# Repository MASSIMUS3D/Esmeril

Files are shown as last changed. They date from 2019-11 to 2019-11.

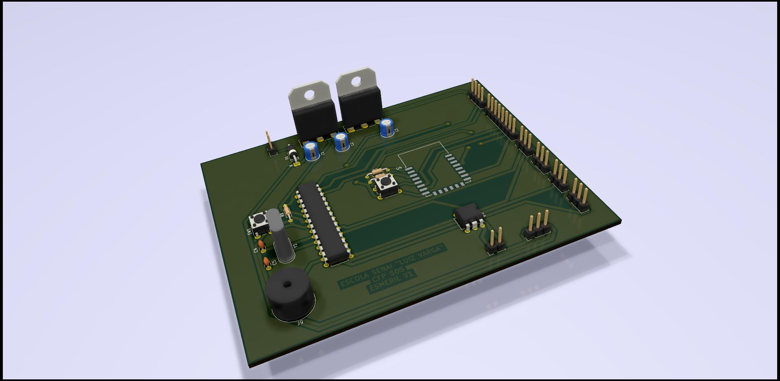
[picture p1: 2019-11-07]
Esmeril-Placa para banca avaliadora/Placa Esmeril.jpg

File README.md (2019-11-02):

# Esmeril
Projeto de adequação de esmeril para NR12 e uso em instituições educacionais
O projeto visa a adequacao de um Esmeril de uso comum para a NR12, tendo em vista os perigos de uso principalmente no ambiente educacionalç,onde os alunos ainda estao aprendendo o uso correto e ainda estao espostos  a ferimentos graves.

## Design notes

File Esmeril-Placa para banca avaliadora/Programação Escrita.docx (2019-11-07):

#include <Servo.h>

#include <U8glib.h>

U8GLIB_SSD1306_128X64 u8g(U8G_I2C_OPT_DEV_0|U8G_I2C_OPT_NO_ACK|U8G_I2C_OPT_FAST);

Servo servo_9;

void setup(){

servo_9.attach(9);

Serial.begin(9600);

pinMode(13, OUTPUT);

servo_9.write(0);

delay(0);

digitalWrite(13,LOW);

pinMode(6, INPUT);

pinMode(5, INPUT);

u8g.firstPage();

do {

u8g.setFont(u8g_font_unifont);

} while( u8g.nextPage());

delay(1000);

pinMode(7, OUTPUT);

pinMode(3, INPUT);

pinMode(4, INPUT);

pinMode(2, INPUT);

}

void loop(){

// INICIA COM SERVO FECHADO E COM O MOTOR DESLIGADO

// LEITURA DO PIR E INFRAVERMELHO.

// TODOS EM NIVEL BAIXO

if (digitalRead(6) == HIGH && digitalRead(5) == LOW) {

// SAUDACAO

u8g.firstPage();

do {

u8g.setPrintPos(0,14);

u8g.print("SENAI");

u8g.setPrintPos(0,30);

u8g.print("");

u8g.setPrintPos(0,46);

u8g.print("LUIZ VARGA");

u8g.setPrintPos(0,62);

u8g.print("");

}

while( u8g.nextPage() );

delay(3000);

while (digitalRead(5) == HIGH) {

Serial.println("Limite de Segurança");

u8g.firstPage();

do {

u8g.setPrintPos(0,14);

u8g.print("MAO");

u8g.setPrintPos(0,30);

u8g.print("PROXIMA");

u8g.setPrintPos(0,46);

u8g.print("AO");

u8g.setPrintPos(0,62);

u8g.print("REBOLO");

}

while( u8g.nextPage() );

digitalWrite(13,LOW);

servo_9.write(0);

delay(1000);

tone(7,131,1000);

}

while (digitalRead(6) == LOW) {

Serial.println("Infravermelho Lateral");

u8g.firstPage();

do {

u8g.setPrintPos(0,14);

u8g.print("USINAGEM");

u8g.setPrintPos(0,30);

u8g.print("LATERAL");

u8g.setPrintPos(0,46);

u8g.print("NAO");

u8g.setPrintPos(0,62);

u8g.print("PERMITIDA");

}

while( u8g.nextPage() );

digitalWrite(13,LOW);

servo_9.write(0);

delay(1000);

tone(7,988,1000);

}

while (digitalRead(3) == LOW) {

Serial.println("Abaixar Proteção");

u8g.firstPage();

do {

u8g.setPrintPos(0,14);

u8g.print("ABAIXAR");

u8g.setPrintPos(0,30);

u8g.print("PROTECAO");

u8g.setPrintPos(0,46);

u8g.print("DE");

u8g.setPrintPos(0,62);

u8g.print("ACRILICO");

}

while( u8g.nextPage() );

digitalWrite(13,LOW);

servo_9.write(0);

delay(1000);

}

while (digitalRead(4) == LOW) {

Serial.println("Posicionar Material");

u8g.firstPage();

do {

u8g.setPrintPos(0,14);

u8g.print("POSICIONAR");

u8g.setPrintPos(0,30);

u8g.print("MATERIAL");

u8g.setPrintPos(0,46);

u8g.print("NO");

u8g.setPrintPos(0,62);

u8g.print("SUPORTE");

}

while( u8g.nextPage() );

digitalWrite(13,LOW);

servo_9.write(0);

delay(1000);

}

while (digitalRead(2) == LOW) {

Serial.println("Aproximar Cartão");

u8g.firstPage();

do {

u8g.setPrintPos(0,14);

u8g.print("APROXIMAR");

u8g.setPrintPos(0,30);

u8g.print("CARTAO");

u8g.setPrintPos(0,46);

u8g.print("NO");

u8g.setPrintPos(0,62);

u8g.print("LEITOR RFID");

}

while( u8g.nextPage() );

digitalWrite(13,LOW);

servo_9.write(0);

delay(1000);

}

delay(1000);

// LEITURA DO PIR E INFRAVERMELHO.

// TODOS EM NIVEL BAIXO

while ((digitalRead(3) && digitalRead(4)) == HIGH && (digitalRead(6) == HIGH && digitalRead(5) == LOW)) {

servo_9.write(160);

delay(1000);

digitalWrite(13,HIGH);

Serial.println("Ligado");

u8g.firstPage();

do {

u8g.setPrintPos(0,14);

u8g.print("REBOLO");

u8g.setPrintPos(0,30);

u8g.print("LIGADO");

u8g.setPrintPos(0,46);

u8g.print("");

u8g.setPrintPos(0,62);

u8g.print("CUIDADO");

}

while( u8g.nextPage() );

}

digitalWrite(13,LOW);

Serial.println("REBOLO EM INERCIA");

u8g.firstPage();

do {

u8g.setPrintPos(0,14);

u8g.print("REBOLO");

u8g.setPrintPos(0,30);

u8g.print("EM");

u8g.setPrintPos(0,46);

u8g.print("INERCIA");

u8g.setPrintPos(0,62);

u8g.print("AGUARDE");

}

while( u8g.nextPage() );

servo_9.write(0);

delay(1000);

tone(7,440,5000);

delay(1000);

tone(7,440,5000);

delay(1000);

tone(7,440,5000);

delay(1000);

} else {

digitalWrite(13,LOW);

Serial.println("Desligado");

servo_9.write(0);

delay(1000);

}

}

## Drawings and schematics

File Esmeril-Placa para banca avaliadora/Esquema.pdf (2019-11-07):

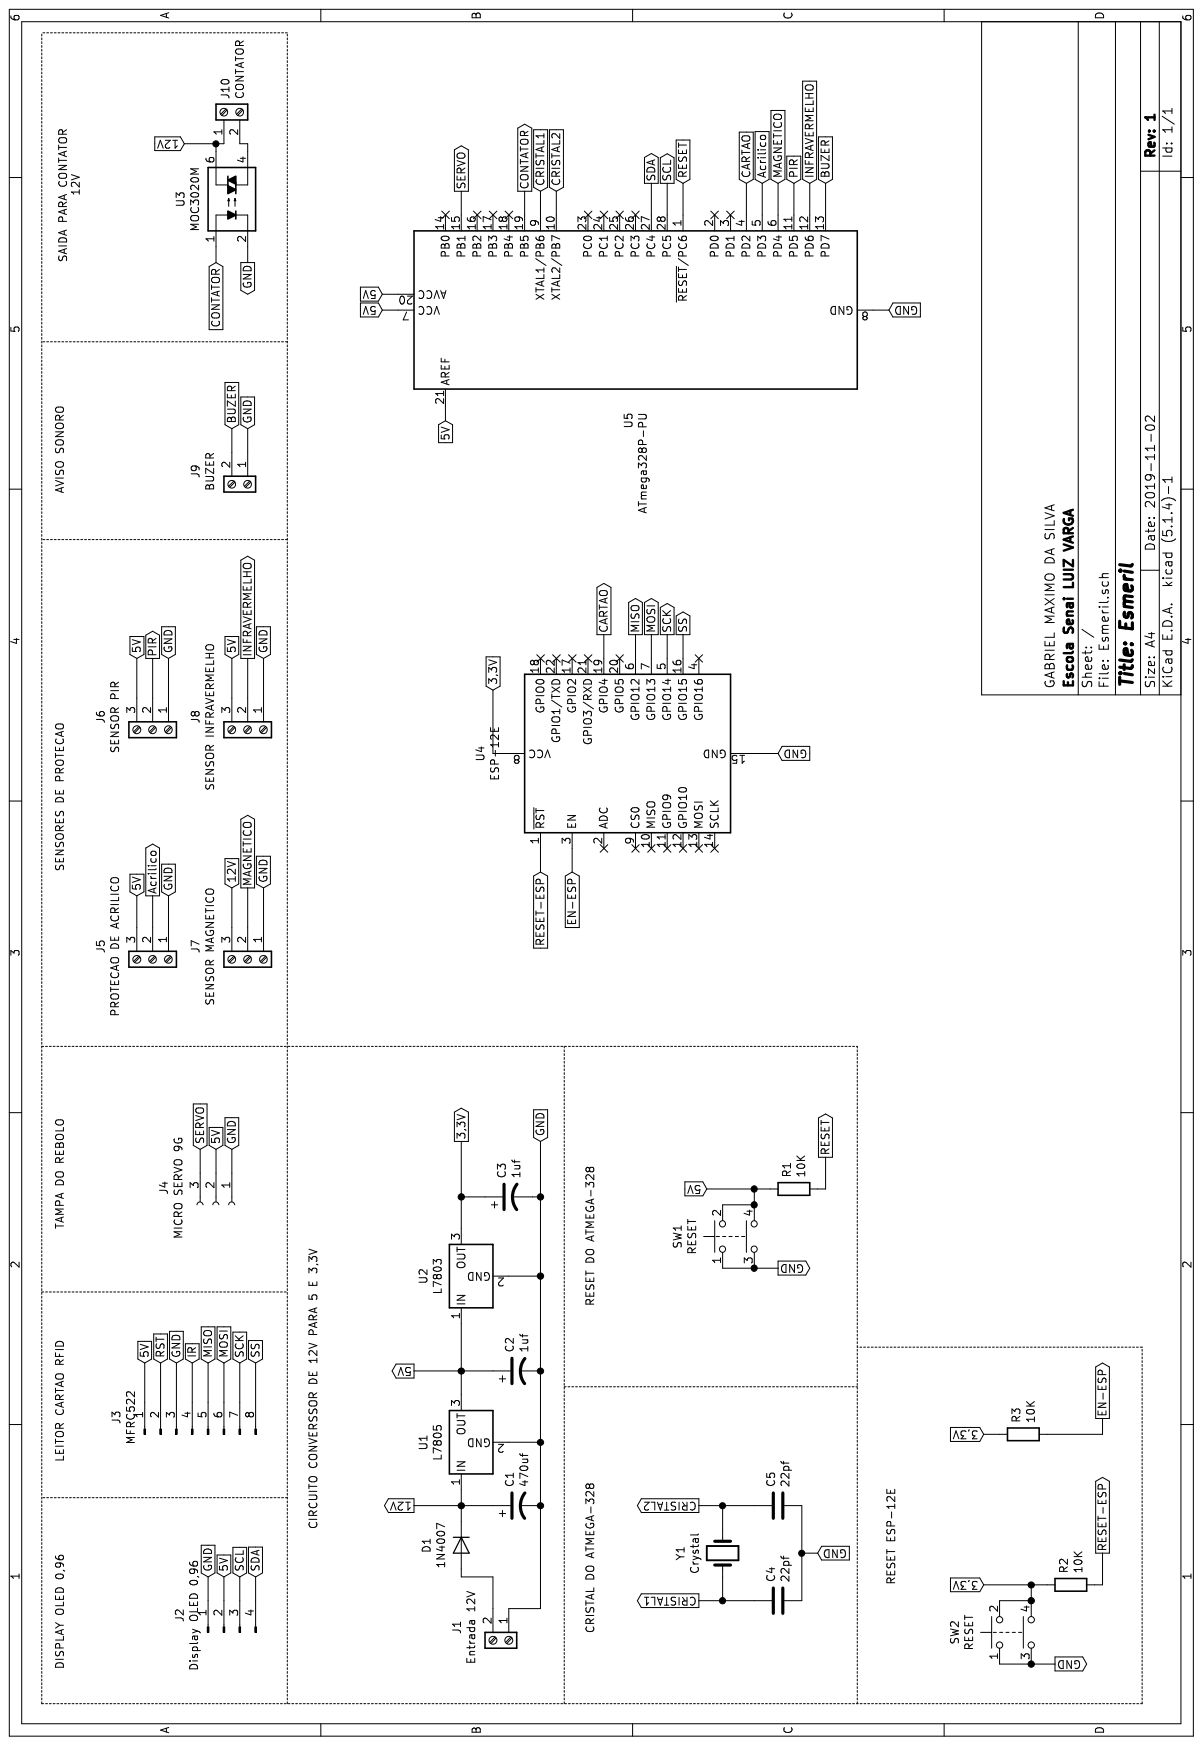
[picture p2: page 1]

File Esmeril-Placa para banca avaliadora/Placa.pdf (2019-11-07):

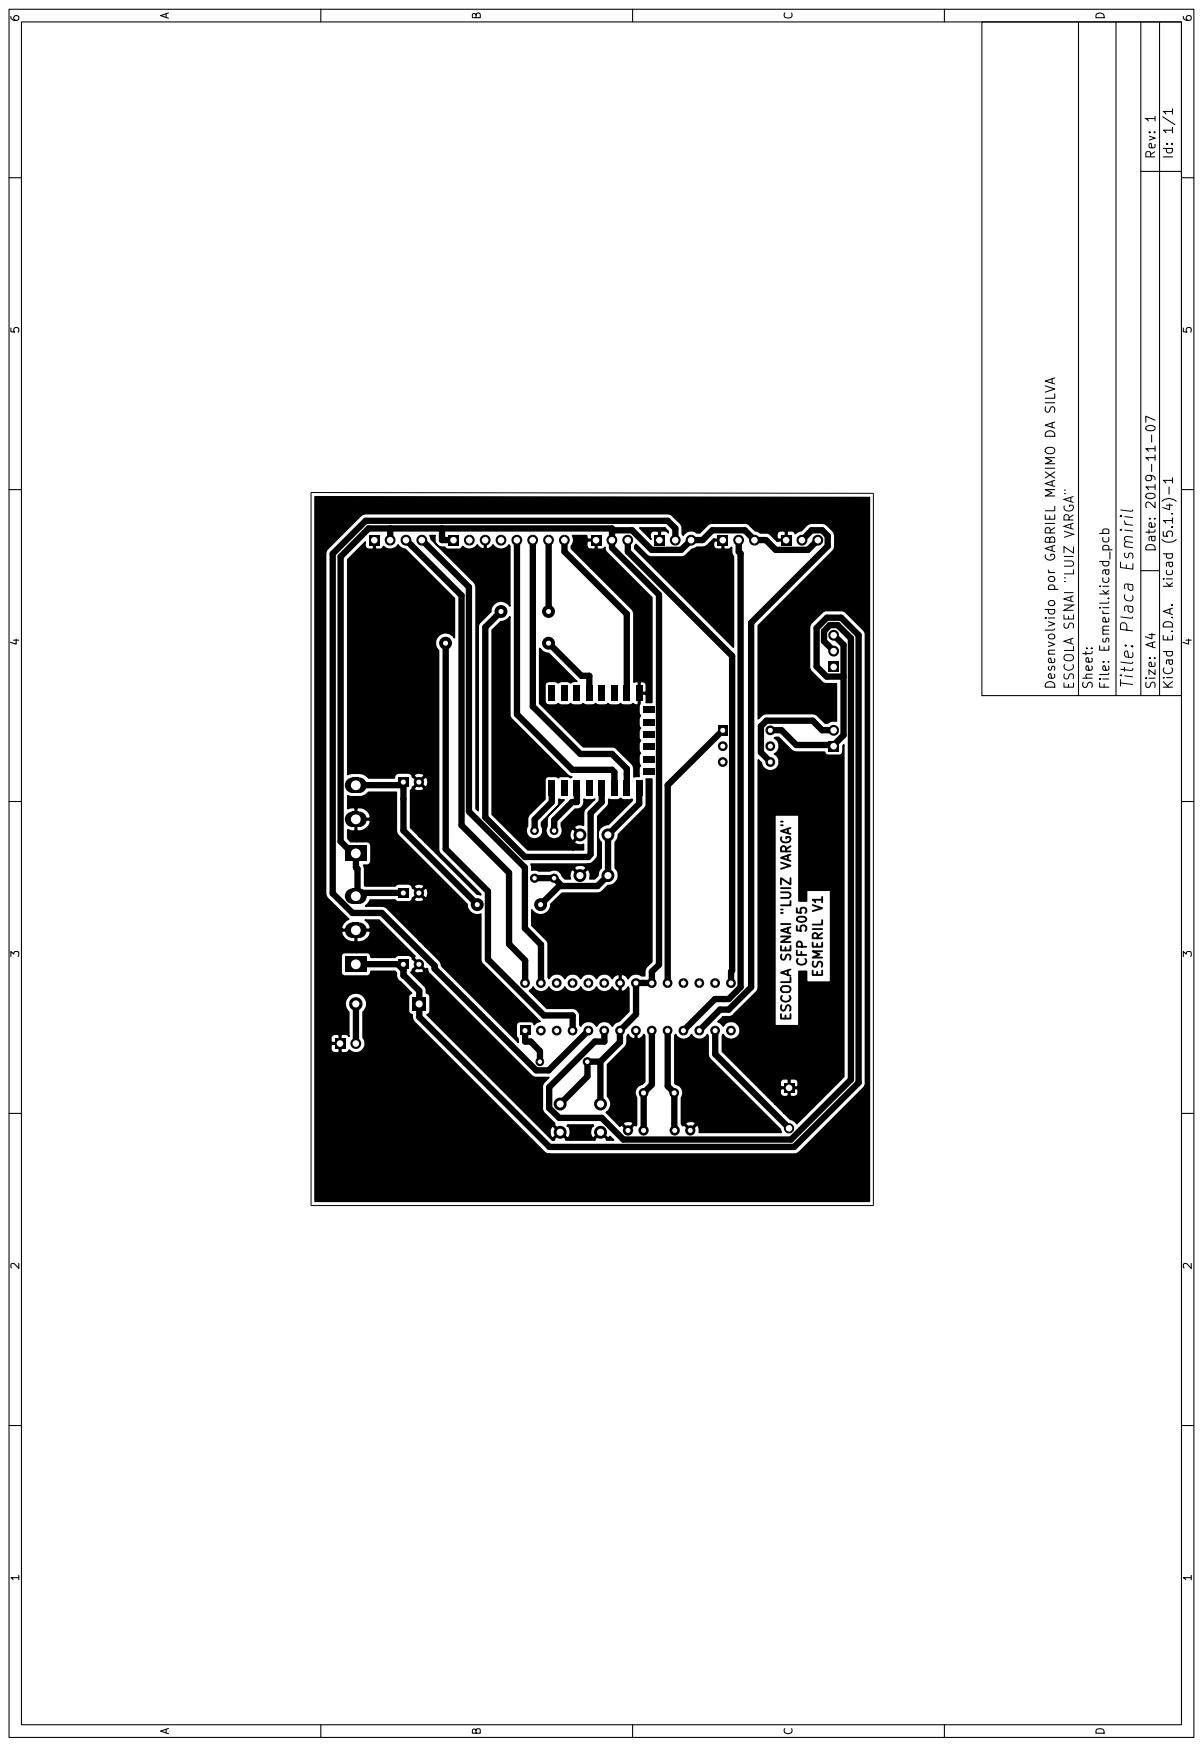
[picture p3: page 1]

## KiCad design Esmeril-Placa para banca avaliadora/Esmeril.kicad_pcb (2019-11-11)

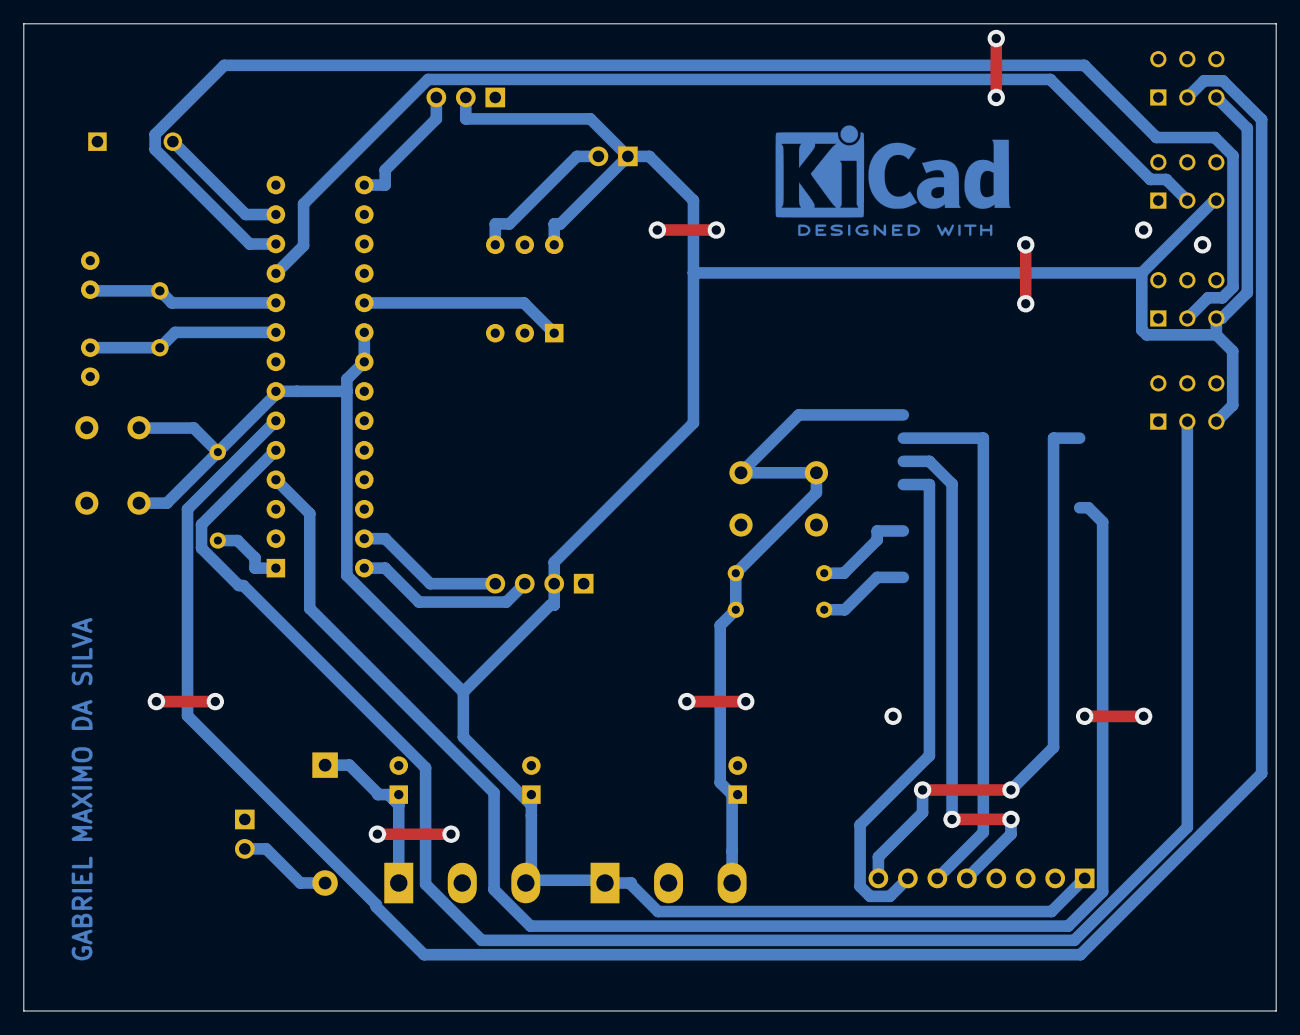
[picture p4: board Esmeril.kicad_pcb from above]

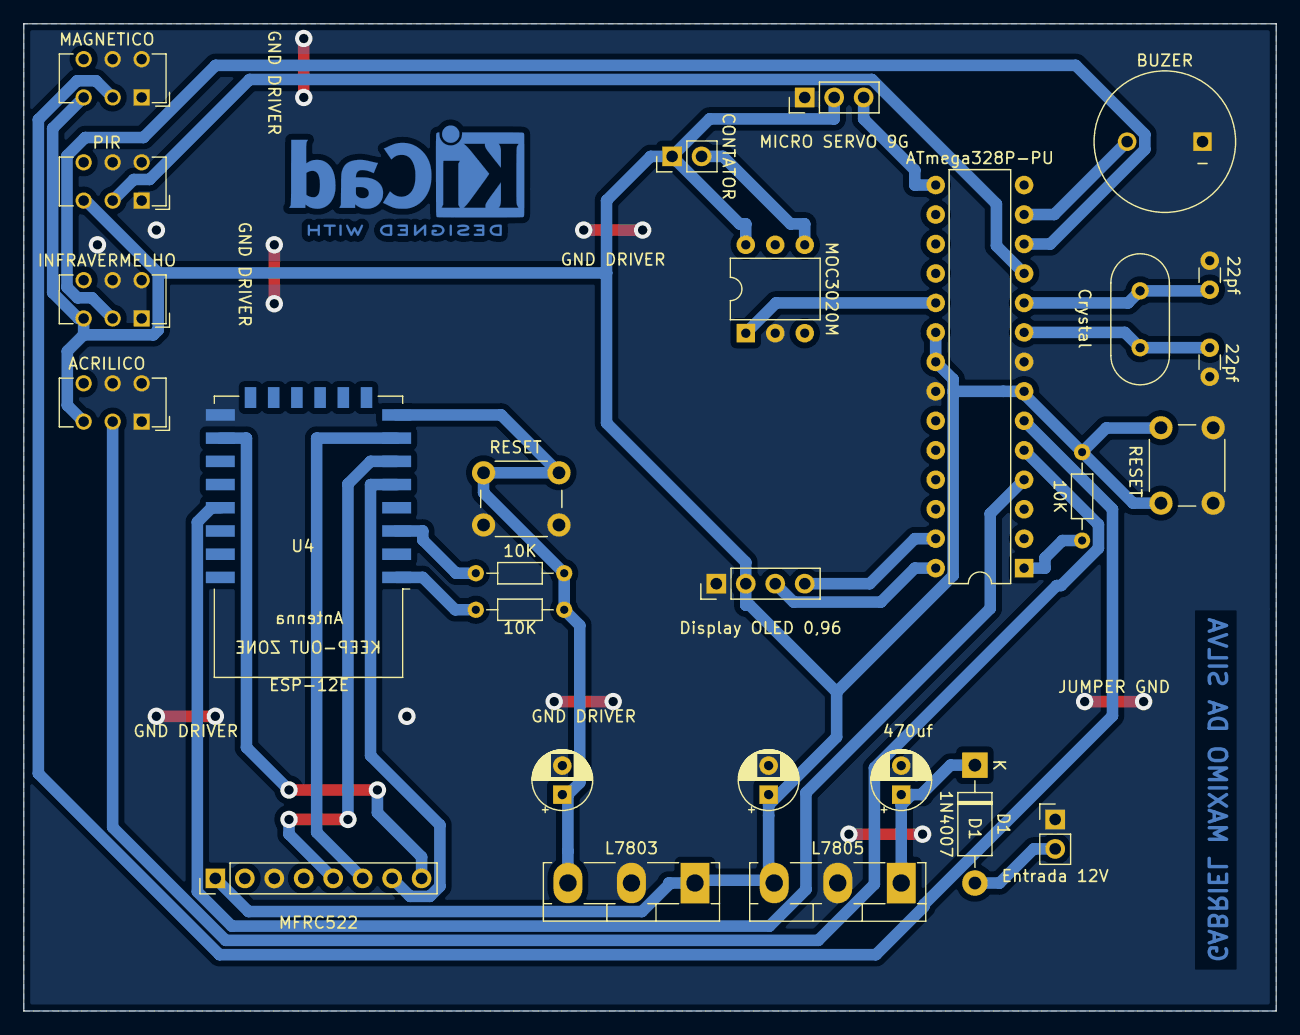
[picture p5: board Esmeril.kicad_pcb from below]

Board: 2 copper layers, 108.0 x 85.1 mm, 27 parts (27 on the bottom side), 25 nets.

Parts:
C1: 470uf; CP_Radial_D5.0mm_P2.50mm
C2, C3: 1uf; CP_Radial_D5.0mm_P2.50mm
C4, C5: 22pf; C_Disc_D3.0mm_W1.6mm_P2.50mm
D1: 1N4007; D_DO-41_SOD81_P10.16mm_Horizontal
J1: Entrada 12V; PinHeader_1x02_P2.54mm_Vertical
J2: Display OLED 0,96; PinHeader_1x04_P2.54mm_Vertical
J3: MFRC522; PinHeader_1x08_P2.54mm_Vertical
J4: MICRO SERVO 9G; PinHeader_1x03_P2.54mm_Vertical
J9: BUZER; MagneticBuzzer_ProSignal_ABT-410-RC
J10: CONTATOR; PinHeader_1x02_P2.54mm_Vertical
R1, R2, R3: 10K; R_Axial_DIN0204_L3.6mm_D1.6mm_P7.62mm_Horizontal
SW1, SW2: RESET; SW_PUSH_6mm
SW3: ACRILICO; SW_CuK_JS202011CQN_DPDT_Straight
SW4: INFRAVERMELHO; SW_CuK_JS202011CQN_DPDT_Straight
SW5: PIR; SW_CuK_JS202011CQN_DPDT_Straight
SW6: MAGNETICO; SW_CuK_JS202011CQN_DPDT_Straight
U1: L7805; TO-218-3_Vertical
U2: L7803; TO-218-3_Vertical
U3: MOC3020M; DIP-6_W7.62mm
U4: ESP-12E
U5: ATmega328P-PU; DIP-28_W7.62mm
Y1: Crystal; Crystal_HC18-U_Vertical

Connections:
3,3V: C3.1, R2.1, R3.1, SW2.2, U2.3, U4.8
5V: C2.1, J2.2, J3.1, J4.2, J10.1, R1.1, SW1.2, SW3.3, SW4.3, SW5.3, SW6.3, U1.3, U2.1, U3.6, U5.7, U5.20, U5.21
12V: C1.1, D1.1, U1.1
Acrilico: SW3.2, U5.5
BUZER: J9.2, U5.13
CARTAO: U4.19, U5.4
CONTATOR: U3.1, U5.19
CRISTAL1: C4.1, U5.9, Y1.1
CRISTAL2: C5.1, U5.10, Y1.2
EN-ESP: R3.2, U4.3
GND: C1.2, C2.2, C3.2, C4.2, C5.2, J1.1, J2.1, J3.3, J4.1, J9.1, SW1.1, SW2.1, SW3.1, SW3.4, SW3.5, SW4.1, SW4.4, SW4.5, SW5.1, SW5.4, SW5.5, SW6.1, SW6.4, SW6.5, U1.2, U2.2, U3.2, U4.15, U5.8, U5.22
INFRAVERMELHO: SW4.2, U5.12
MAGNETICO: SW6.2, U5.6
MISO: J3.5, U4.6
MOSI: J3.6, U4.7
unnamed: D1.2, J1.2
unnamed: J10.2, U3.4
PIR: SW5.2, U5.11
RESET: R1.2, U5.1
RESET-ESP: R2.2, U4.1
SCK: J3.7, U4.5
SCL: J2.3, U5.28
SDA: J2.4, U5.27
SERVO: J4.3, U5.15
SS: J3.8, U4.16

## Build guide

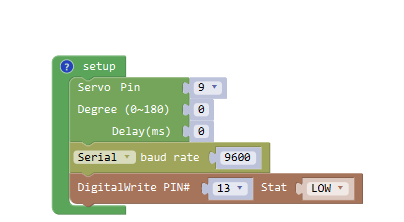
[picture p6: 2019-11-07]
Fotos Programação em bloco/Setup.PNG
